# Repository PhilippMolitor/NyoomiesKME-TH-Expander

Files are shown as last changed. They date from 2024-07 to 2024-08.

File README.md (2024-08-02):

# NyoomiesKME TH Expander
An expander board for the [Nyoomies](https://github.com/comradef191/NyoomiesKME) klipper motor expansion.

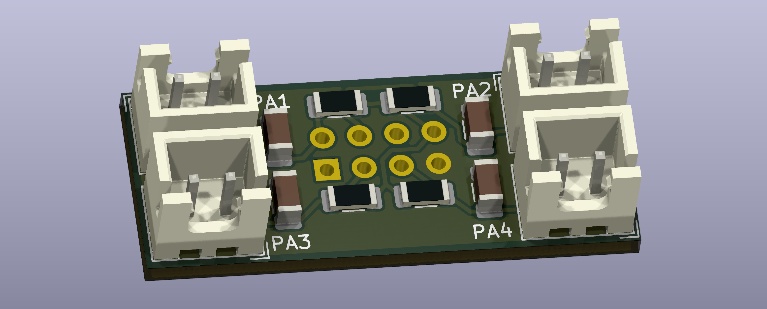
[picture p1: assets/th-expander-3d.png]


# BOM
1. 4x 1206 2.2k 1% resistor
2. 4x 1206 10uF capacitor
3. 4x JST-SH 2pin socket
4. 1x 2.54mm 2x4pin socket

# Klipper configuration
See the [example configuration](nyoomies-th-expander.cfg) for reference.

# Schematic
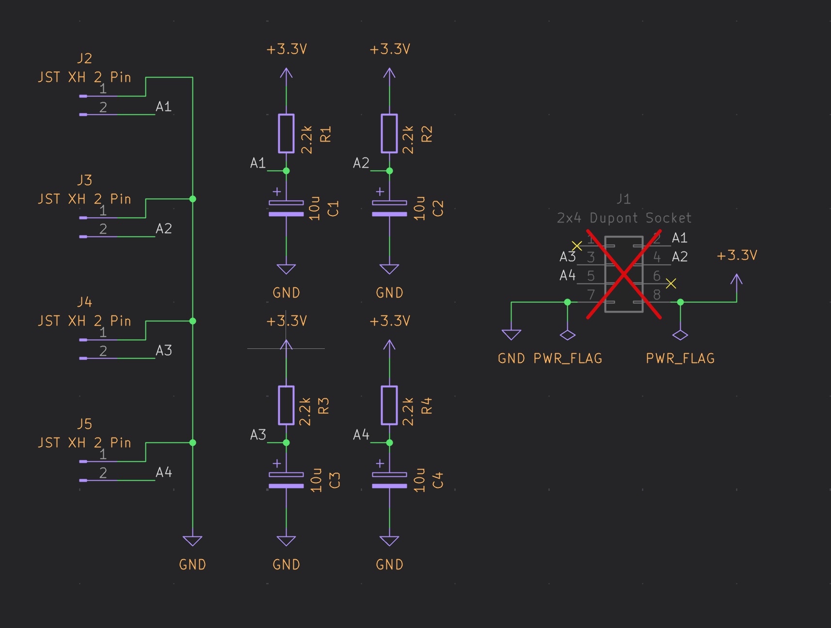
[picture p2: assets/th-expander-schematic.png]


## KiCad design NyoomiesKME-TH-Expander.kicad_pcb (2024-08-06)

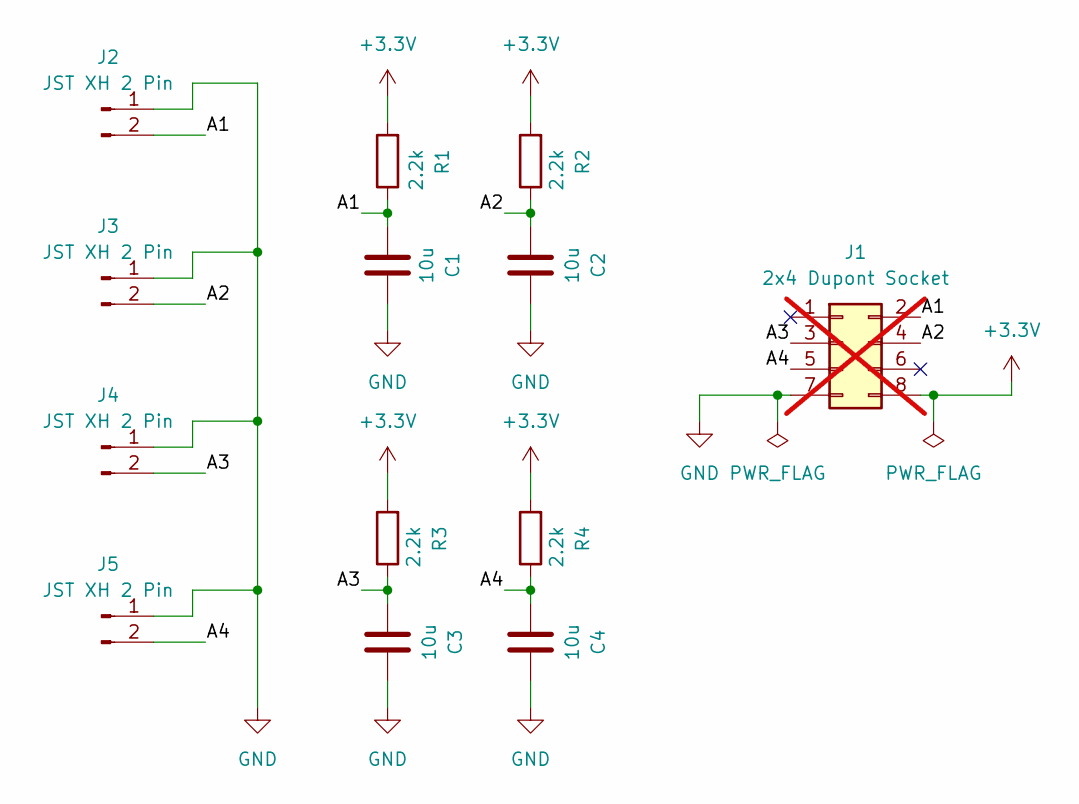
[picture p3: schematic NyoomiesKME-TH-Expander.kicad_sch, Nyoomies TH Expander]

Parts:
C1, C2, C3, C4: 10u; C_1206_3216Metric; LCSC Part # C47971
J1: 2x4 Dupont Socket; PinSocket_2x04_P2.54mm_Vertical; not fitted
J2, J3, J4, J5: JST XH 2 Pin; JST_XH_B2B-XH-A_1x02_P2.50mm_Vertical; LCSC Part # C158012
R1, R2, R3, R4: 2.2k; R_1206_3216Metric; LCSC Part # C311944

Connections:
+3.3V: J1.8, R1.2, R2.2, R3.2, R4.2
/A1: C1.1, J1.2, J2.2, R1.1
/A2: C2.1, J1.4, J3.2, R2.1
/A3: C3.1, J1.3, J4.2, R3.1
/A4: C4.1, J1.5, J5.2, R4.1
GND: C1.2, C2.2, C3.2, C4.2, J1.7, J2.1, J3.1, J4.1, J5.1

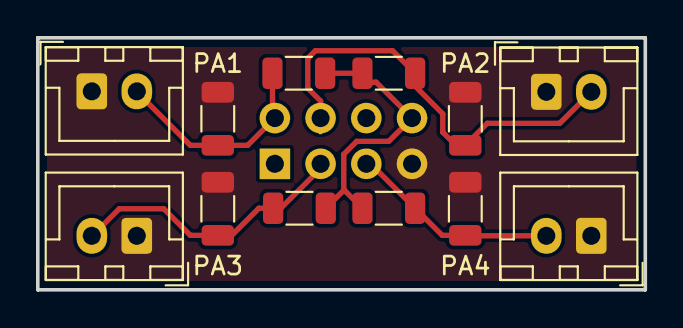
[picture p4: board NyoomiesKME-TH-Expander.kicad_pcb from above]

Board: 2 copper layers, 33.8 x 14.0 mm, 13 parts (1 on the bottom side), 6 nets.

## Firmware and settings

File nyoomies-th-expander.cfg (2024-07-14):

# This should already be in your config
# Adjust all pin names to your MCU name!
# This only works with the BlackPill MCU, not with the Pi Pico!
[mcu nyoomies]
serial: /dev/by-id/usb-1a86_USB2.0-Serial-if00-port0

# Example for NTC100K thermistors
[temperature_sensor nyoomies_th_1]
sensor_pin: nyoomies:PA1
pullup_resistor: 2200

sensor_type: Generic 3950
#   One of "EPCOS 100K B57560G104F", "ATC Semitec 104GT-2",
#   "ATC Semitec 104NT-4-R025H42G", "Generic 3950",
#   "Honeywell 100K 135-104LAG-J01", "NTC 100K MGB18-104F39050L32",
#   "SliceEngineering 450", or "TDK NTCG104LH104JT1"
min_temp: 0
max_temp: 150

# Example for NTC100K thermistors
[temperature_sensor nyoomies_th_2]
sensor_pin: nyoomies:PA2
pullup_resistor: 2200

sensor_type: Generic 3950
#   One of "EPCOS 100K B57560G104F", "ATC Semitec 104GT-2",
#   "ATC Semitec 104NT-4-R025H42G", "Generic 3950",
#   "Honeywell 100K 135-104LAG-J01", "NTC 100K MGB18-104F39050L32",
#   "SliceEngineering 450", or "TDK NTCG104LH104JT1"
min_temp: 0
max_temp: 150

# Example for PT1000 thermistors
[temperature_sensor nyoomies_th_3]
sensor_pin: nyoomies:PA3
pullup_resistor: 2200

sensor_type: PT1000
min_temp: 0
max_temp: 350

# Example for PT1000 thermistors
[temperature_sensor nyoomies_th_4]
sensor_pin: nyoomies:PA4
pullup_resistor: 2200

sensor_type: PT1000
min_temp: 0
max_temp: 350

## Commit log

2024-07-11 smaller routing fixes, relocate R3 R4
    [NyoomiesKME-NTC-Expander.kicad_pcb]
2024-07-11 rev 0.2: add filter caps
    [NyoomiesKME-NTC-Expander.kicad_pcb, NyoomiesKME-NTC-Expander.kicad_sch]
2024-07-11 switch to 2.2k, fix pcb DRC
    [NyoomiesKME-NTC-Expander.kicad_pcb, NyoomiesKME-NTC-Expander.kicad_sch]
2024-07-11 rename to TH Expander
    [NyoomiesKME-TH-Expander.kicad_pcb, NyoomiesKME-TH-Expander.kicad_sch]
2024-07-11 add sheet info to pcb doc
    [NyoomiesKME-TH-Expander.kicad_pcb]
2024-07-11 add example config for klipper
    [nyoomies-th-expander.cfg]
2024-07-11 fix capacitor part no.
    [NyoomiesKME-TH-Expander.kicad_pcb, NyoomiesKME-TH-Expander.kicad_sch]
2024-07-11 add gerber_to_order
2024-07-14 switch to 2.2k resistors for example config
    [nyoomies-th-expander.cfg]
2024-07-19 use filtering caps correctly and use labels instead of global labels
    [NyoomiesKME-TH-Expander.kicad_pcb, NyoomiesKME-TH-Expander.kicad_sch]
2024-07-19 minor routing improvements
    [NyoomiesKME-TH-Expander.kicad_pcb]
2024-07-19 switch to unpolarized caps
    [NyoomiesKME-TH-Expander.kicad_pcb, NyoomiesKME-TH-Expander.kicad_sch]
2024-08-06 rev 0.3 - change header position, improve silkscreen
    [NyoomiesKME-TH-Expander.kicad_pcb, NyoomiesKME-TH-Expander.kicad_sch]
2024-08-10 update 3d pcb asset to rev 0.3
